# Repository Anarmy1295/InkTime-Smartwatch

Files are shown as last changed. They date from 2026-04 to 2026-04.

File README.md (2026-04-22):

# InkTime-Smartwatch

An open-source smartwatch powered by the nRF52840 with an e-paper display, designed for low power consumption and BLE connectivity.



## Block Diagram

Untitled Diagram drawio

## BOM (Bill Of Materials) 
| Qty | Component | Value / Part | Package | Notes |
|-----|---|---|---|---|
| 3 | Buttons | EVP-AKE31A | SMD | SW_DN, SW_ENT, SW_UP |
| 1 | Solder Jumper | SJ1 | SMD | Configuration jumper |
| 3 | Resistor | 7.68kΩ | 0201 | R2, R3, R4 |
| 4 | Capacitor | 0.1µF | 0201 | Decoupling |
| 1 | Capacitor | 0.1µF / 50V | 0402 | EPD |
| 1 | Resistor | 0Ω / 0.47Ω | 0201 | EPD driver |
| 1 | Capacitor | 1µF | 0402 | General |
| 5 | Capacitor | 100nF | 0402 | Decoupling |
| 1 | Capacitor | 100pF | 0402 | Filtering |
| 6 | Resistor | 10kΩ | 0201 | Pull-ups / general |
| 1 | Capacitor | 10µF | 0201 | Bulk |
| 2 | Capacitor | 10µF | 0402 | Power |
| 1 | Inductor | 10µH | 0402 | DC/DC |
| 4 | Capacitor | 12pF | 0402 | Crystal load |
| 1 | Inductor | 15nH | 0402 | RF matching |
| 2 | Capacitor | 1pF | 0402 | RF |
| 6 | Capacitor | 1µF | 0201 | Decoupling |
| 9 | Capacitor | 1µF / 50V | 0402 | EPD |
| 1 | Resistor | 2.2kΩ | 0201 | Config |
| 1 | PMOS | DMG2305UX | SOT-23 | Power switching |
| 2 | Capacitor | 22µF | 0402 | Power rail |
| 1 | Antenna | 2450AT18B100E | 1206 | 2.4GHz |
| 1 | Inductor | 3.9nH | 0402 | RF matching |
| 1 | Crystal | 32.768kHz | 3215 | RTC |
| 1 | Crystal | 32MHz | 2016 | MCU clock |
| 2 | Resistor | 3.3kΩ | 0201 | General |
| 1 | Capacitor | 4.7µF | 0402 | Bulk |
| 5 | Capacitor | 4.7µF | 0402 | Decoupling |
| 1 | Capacitor | 47nF | 0402 | Filtering |
| 1 | FPC Connector | 503480-2400 | SMD | Display |
| 2 | Resistor | 5.1kΩ | 0201 | USB-C CC |
| 1 | Inductor | 68µH | SMD | Power |
| 1 | Capacitor | 820pF | 0402 | Filtering |
| 1 | Accelerometer | BMA421 | LGA | Sensor |
| 1 | Charger IC | BQ25180YBGR | BGA | LiPo charger |
| 1 | Haptic Driver | DRV2605YZFR | BGA | Motor driver |
| 1 | Inductor | 0.47µH | 2012 | Power stage |
| 14 | Test Points | TP pads | PCB | Debug |
| 1 | USB-C | KH-TYPE-C-16P | SMD | Power |
| 1 | Fuel Gauge | MAX17048G+T10 | TDFN-8 | Battery monitor |
| 3 | Diode | MBR0530 | SOD-123 | Schottky |
| 3 | Capacitor | N.C. | 0402 | Not populated |
| 1 | MCU | nRF52840 | QFN | Main MCU |
| 1 | Buck-Boost | RT6160AWSC | WLCSP | 3.3V rail |
| 1 | NMOS | SI1308EDL | SOT-323 | Switching |
| 1 | Debug Connector | TC2030-IDC | PCB | SWD |
| 1 | ESD Protection | USBLC6-2SC6Y | SOT-23-6 | USB protection |

## Hardware Description

### MCU — nRF52840

The nRF52840 is the central processing unit of the system.

**Key features:**
- ARM Cortex-M4F @ 64 MHz (with FPU)
- Bluetooth Low Energy (BLE 5.0)
- USB 2.0 Full Speed
- 1 MB Flash / 256 KB RAM

All peripherals are connected via:
- I2C
- SPI
- GPIO

---

### Power Architecture

USB-C → BQ25180 (charger) → LiPo battery (AKY0106, 400 mAh)
→ 3.3V rail (VREG, for MCU and all peripherals)

Battery → RT6160AWSC (boost) → EPD high-voltage supply (VCOM, gate voltages)

#### BQ25180 (Charger IC)

- Charges the LiPo battery
- Provides system rail (VSYS)
- I2C communication with MCU
- Interrupt output for status/fault

#### RT6160 (Buck-Boost Regulator)

- Converts VSYS to stable 3.3V
- Powers:
  - MCU
  - sensors
  - display
  - haptic driver

#### MAX17048 (Fuel Gauge)

- Monitors battery voltage and state of charge
- I2C interface
- ALERT signal for battery events

---

### E-Paper Display

Controlled via SPI and GPIO.

#### Interface

| Signal | Direction | Description |
|---|---|---|
| SCK | MCU → Display | SPI clock |
| MOSI | MCU → Display | SPI data |
| EPD_CS | MCU → Display | Chip select |
| EPD_DC | MCU → Display | Data/Command |
| EPD_RST | MCU → Display | Reset |
| EPD_BUSY | Display → MCU | Status |

#### Power Stage

Includes:
- inductors
- Schottky diodes
- MOSFETs

Generates:
- PREVGH
- PREVGL

---

### IMU — BMA421

- Interface: I2C
- Features:
  - acceleration sensing
  - motion detection
  - step counting

**Interrupts:**
- INT1
- INT2

---

### Haptic Driver — DRV2605

- Interface: I2C
- Enable pin: `HAPTIC_EN`
- Function: vibration motor control

---

### USB Interface

- USB Type-C connector
- ESD protection: USBLC6-2SC6Y

**Signals:**
- VBUS
- D+
- D-

**Usage:**
- charging
- USB detection

---

### RF & Antenna

- 2.4 GHz chip antenna (2450AT18B100E)

**Design includes:**
- matching network
- antenna keepout
- no copper under antenna

---

### User Interface

3 buttons:
- Up
- Down
- Enter / Esc

- Connected to GPIO
- Active-low

---

### Debug Interface

SWD via Tag-Connect:

- SWDIO
- SWDCLK
- RESET
- SWO
- 3.3V
- GND

---

## Pin Mapping (nRF52840)

### I2C (Shared Bus)

| Pin | Function |
|-----|---|
| P0.06 | SDA |
| P0.07 | SCL |

Devices:
- BMA421
- MAX17048
- BQ25180
- RT6160
- DRV2605

---

### SPI (E-Paper Display)

| Pin | Function |
|-----|---|
| P0.02 | SCK |
| P0.03 | MOSI |
| P0.05 | CS |
| P0.15 | DC |
| P0.16 | RST |
| P0.17 | BUSY |

---

### Control & Interrupts

| Pin | Function |
|-----|---|
| P1.01 | Display power (PFET) |
| P0.08 | BMA421 INT1 |
| P1.08 | BMA421 INT2 |
| P0.10 | MAX17048 ALERT |
| P0.11 | Charger interrupt |
| P0.12 | Haptic enable |

---

### Buttons

| Pin | Function |
|-----|---|
| P0.13 | Up |
| P0.14 | Down |
| P1.00 | Enter / Esc |

---

### USB

| Signal | Function |
|---|---|
| D+ | Data |
| D- | Data |
| VBUS | Power detect |

---

### Clocks & Debug

- SWDIO / SWDCLK / RESET / SWO
- 32 MHz crystal (HFXO)
- 32.768 kHz crystal (LFXO)

---

## Design Considerations

- Use of dedicated hardware interfaces (I2C, SPI)
- Logical grouping of signals
- Simplified PCB routing
- Interrupt-driven architecture
- Clean debug interface

---

## Power Optimization

- MCU supports low-power modes
- E-paper consumes power only during refresh
- IMU is ultra low-power
- Haptic driver active only briefly

**Efficiency strategies:**
- enable peripherals only when needed
- regulated 3.3V rail
- independent control of display power

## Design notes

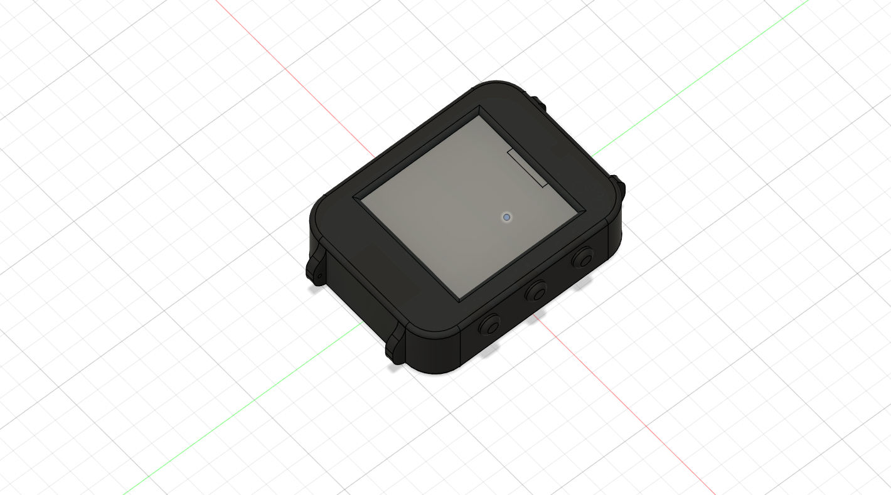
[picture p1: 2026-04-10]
Images/Case.png

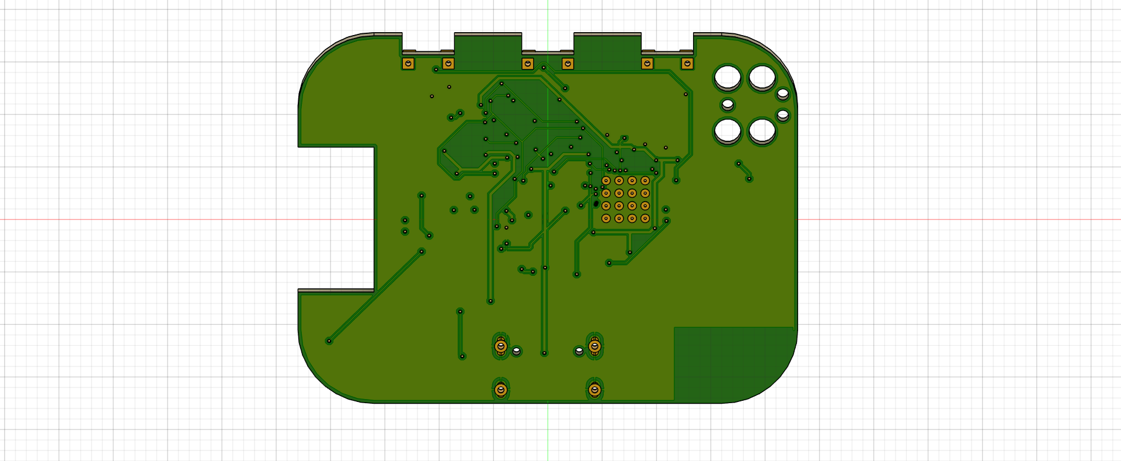
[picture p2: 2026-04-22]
Images/InkTime2.png

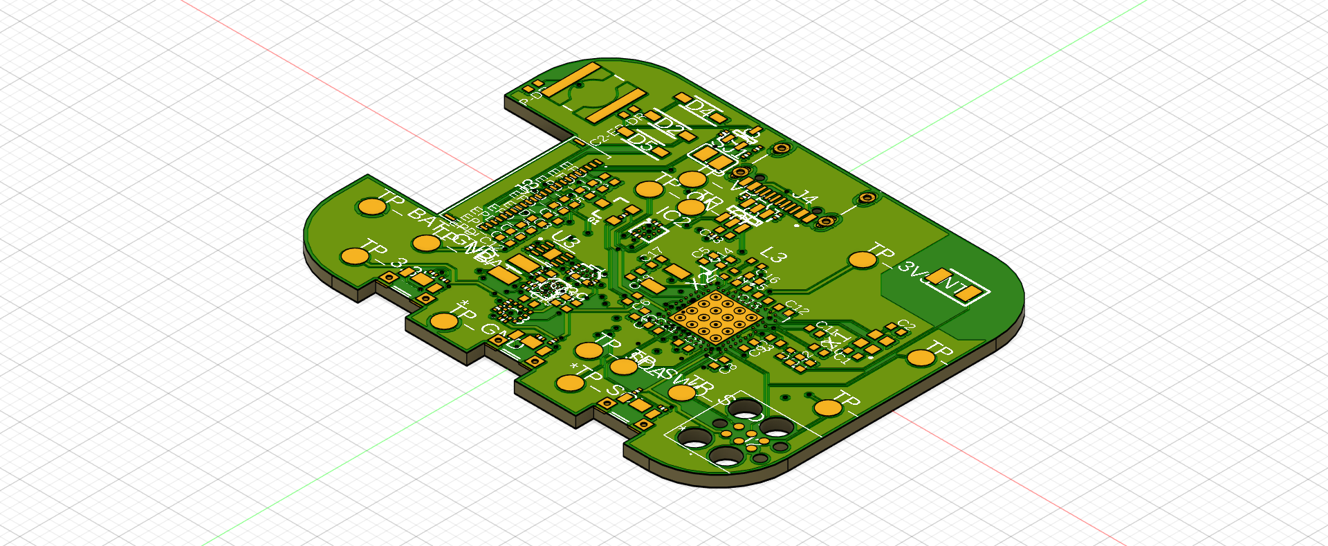
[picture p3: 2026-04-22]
Images/InkTime.png

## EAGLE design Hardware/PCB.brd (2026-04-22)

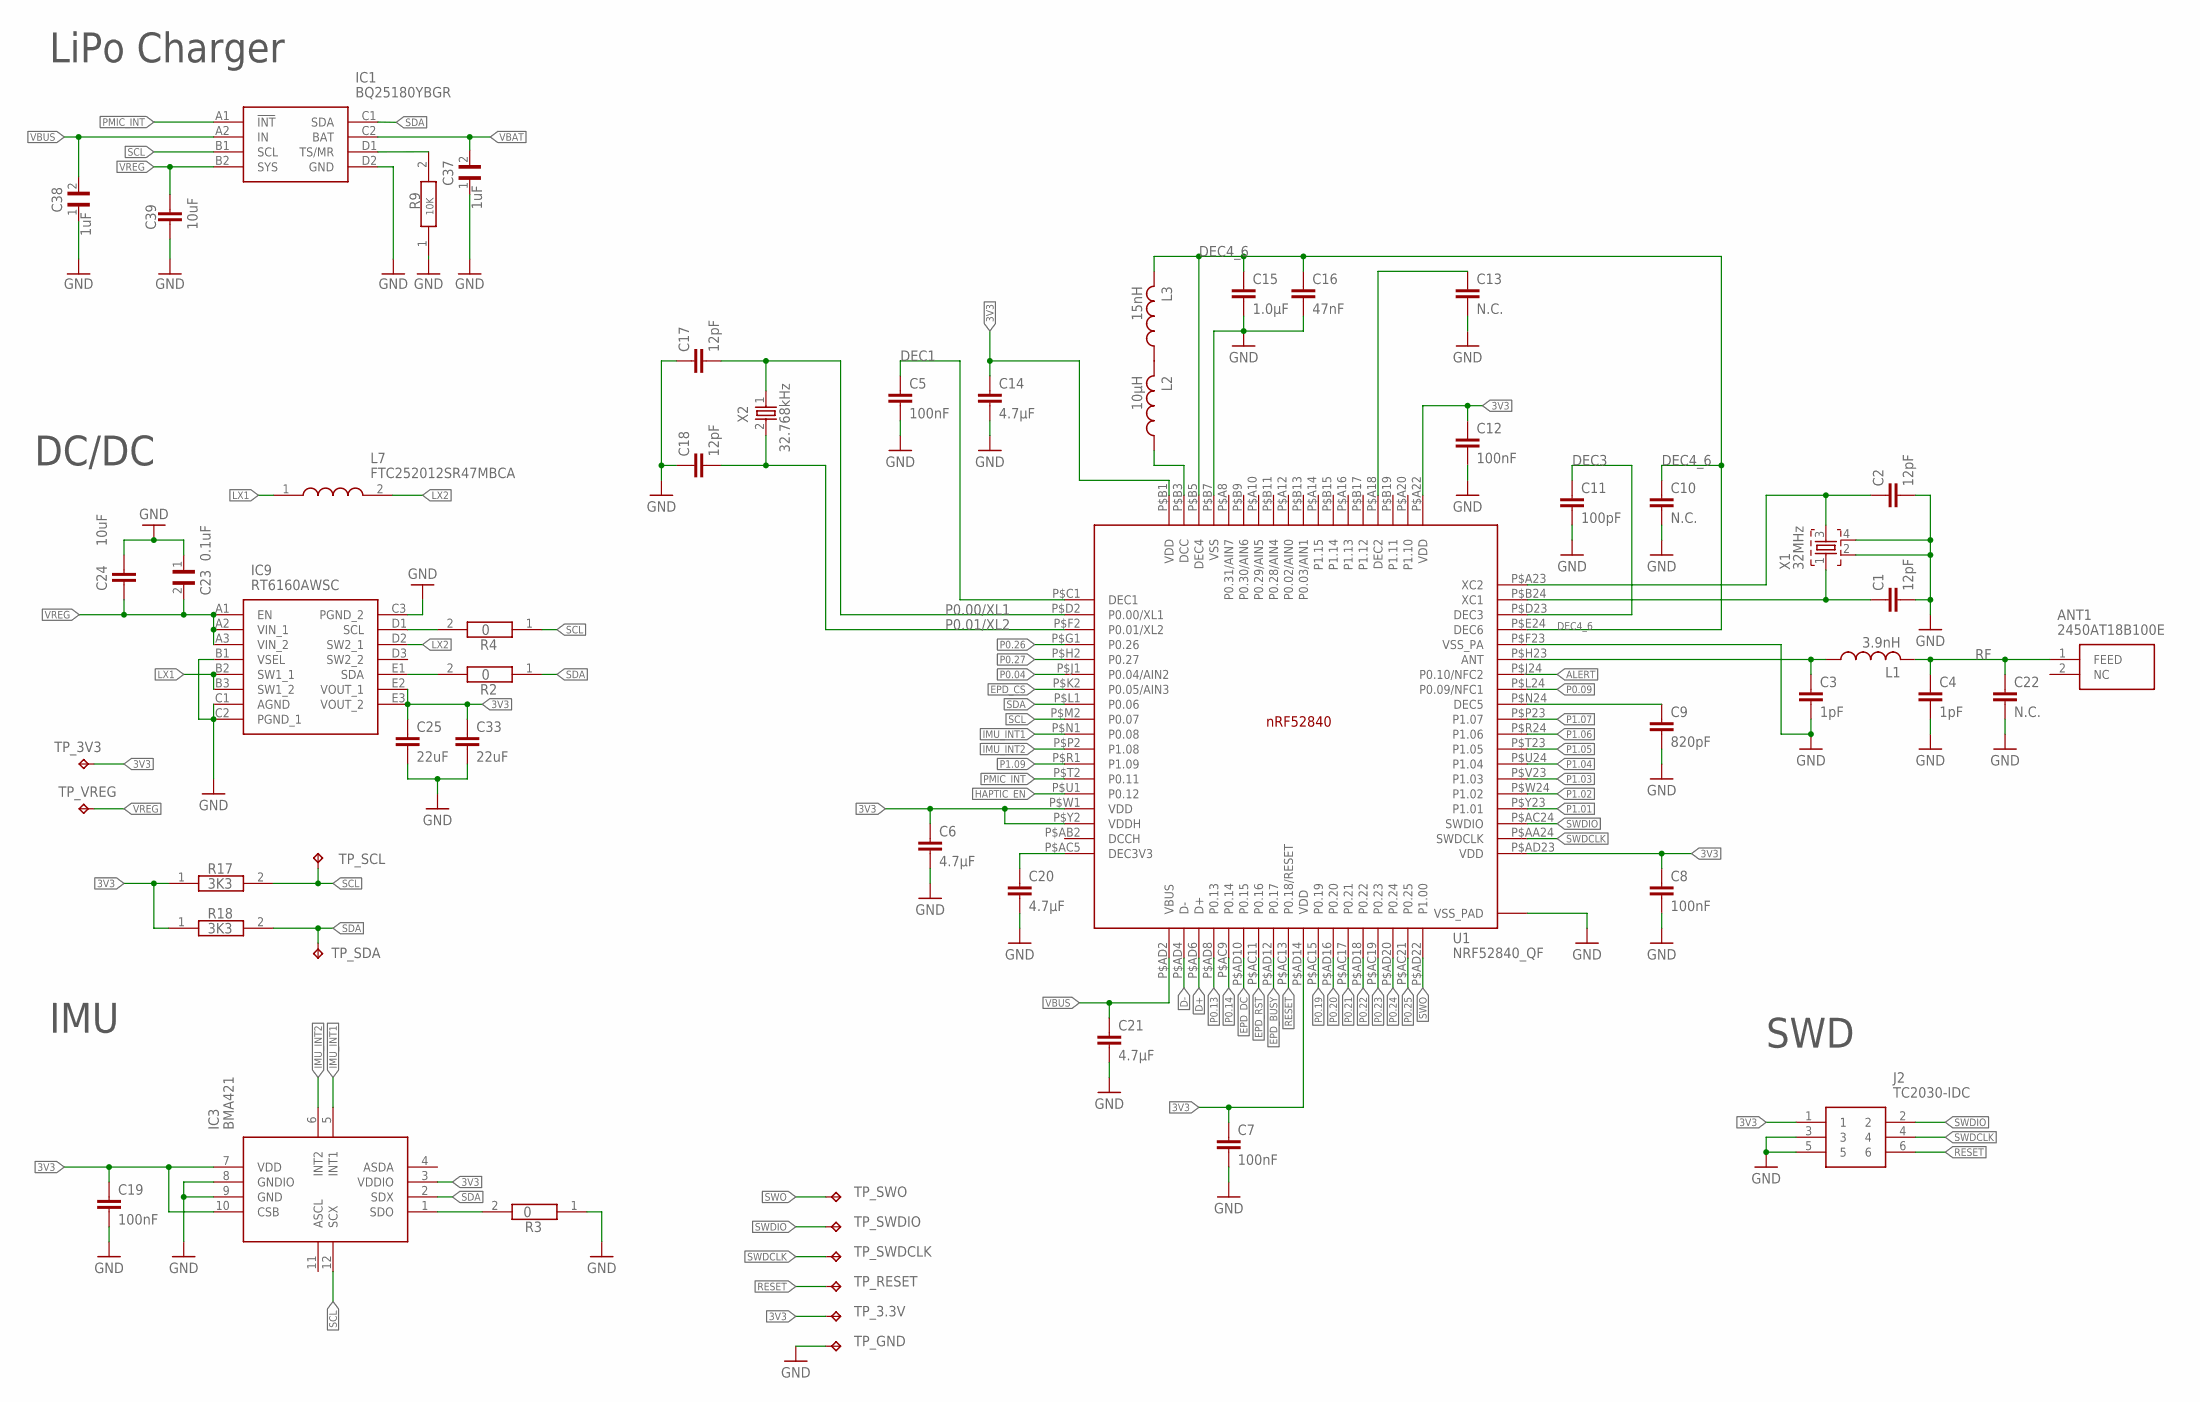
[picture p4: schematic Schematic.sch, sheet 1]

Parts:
ANT1: 2450AT18B100E; 2450AT18B100E_ANTC3216X140N
C1, C2, C17, C18: 12pF; PERFECT_0402_0402
C3, C4: 1pF; PERFECT_0402_0402
C5, C7, C8, C12, C19: 100nF; PERFECT_0402_0402
C6, C14, C20, C21: 4.7μF; PERFECT_0402_0402
C9: 820pF; PERFECT_0402_0402
C10, C13, C22: N.C.; PERFECT_0402_0402
C11: 100pF; PERFECT_0402_0402
C15: 1.0μF; PERFECT_0402_0402
C16: 47nF; PERFECT_0402_0402
C23: 0.1uF; GRM011R60J152KE01L_1_0201
C24: 10uF; PERFECT_0402_0402
C25, C33: 22uF; PERFECT_0402_0402
C37, C38: 1uF; GRM011R60J152KE01L_1_0201
C39: 10uF; NORDIC_NRF_3_RESC0402_N
IC1: BQ25180YBGR; BQ25180YBGR_BGA8C40P2X4_100X155X50
IC3: BMA421; BMA423_BMA423
IC9: RT6160AWSC; RT6160AWSC_BGA15C40P3X5_140X230X60
J2: TC2030-IDC; TC2030-IDC_TC2030IDC
L1: 3.9nH; NORDIC_NRF_2_RESC0402_L
L2: 10μH; NORDIC_NRF_2_RESC0402_L
L3: 15nH; NORDIC_NRF_2_RESC0402_L
L7: FTC252012SR47MBCA; MLP2016SR47MT0S1_INDC2016X100N
R2, R3, R4: 0; CPF0201D7K68C1_0201
R9: 10K; CPF0201D7K68C1_0201
R17, R18: 3K3; CPF0201D7K68C1_0201
TP_3.3V, TP_3V3: HECTOR_WATCH_1_TPTP20R; HECTOR_WATCH_1_TP20R
TP_GND: HECTOR_WATCH_1_TPTP20R; HECTOR_WATCH_1_TP20R
TP_RESET: HECTOR_WATCH_1_TPTP20R; HECTOR_WATCH_1_TP20R
TP_SCL: HECTOR_WATCH_1_TPTP20R; HECTOR_WATCH_1_TP20R
TP_SDA: HECTOR_WATCH_1_TPTP20R; HECTOR_WATCH_1_TP20R
TP_SWDCLK: HECTOR_WATCH_1_TPTP20R; HECTOR_WATCH_1_TP20R
TP_SWDIO: HECTOR_WATCH_1_TPTP20R; HECTOR_WATCH_1_TP20R
TP_SWO: HECTOR_WATCH_1_TPTP20R; HECTOR_WATCH_1_TP20R
TP_VREG: HECTOR_WATCH_1_TPTP20R; HECTOR_WATCH_1_TP20R
U1: NRF52840_QF; NORDIC_NRF_4_AQFN50P700X700X85_HS-74N
X1: 32MHz; NORDIC_NRF_BT-XTAL_2016_N
X2: 32.768kHz; NORDIC_NRF_1_XTAL_3215_N

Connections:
3V3: C6.1, C7.1, C8.1, C12.1, C14.1, C19.1, C25.1, C33.1, IC3.3 (VDDIO), IC3.7 (VDD), IC3.10 (CSB), IC9.E2 (VOUT_1), IC9.E3 (VOUT_2), J2.1, R17.1, R18.1, TP_3.3V.TP, TP_3V3.TP, U1.P$A22 (VDD), U1.P$AD14 (VDD), U1.P$AD23 (VDD), U1.P$B1 (VDD), U1.P$W1 (VDD), U1.P$Y2 (VDDH); also elsewhere on the board
ALERT: U1.P$J24 (P0.10/NFC2); also elsewhere on the board
D+: U1.P$AD6 (D+); also elsewhere on the board
D-: U1.P$AD4 (D-); also elsewhere on the board
DEC1: C5.1, U1.P$C1 (DEC1)
DEC3: C11.1, U1.P$D23 (DEC3)
DEC4_6: C10.1, C15.1, C16.1, L3.2, U1.P$B5 (DEC4), U1.P$E24 (DEC6)
EPD_BUSY: U1.P$AD12 (P0.17); also elsewhere on the board
EPD_CS: U1.P$K2 (P0.05/AIN3); also elsewhere on the board
EPD_DC: U1.P$AD10 (P0.15); also elsewhere on the board
EPD_RST: U1.P$AC11 (P0.16); also elsewhere on the board
GND: C1.2, C2.2, C3.2, C4.2, C5.2, C6.2, C7.2, C8.2, C9.2, C10.2, C11.2, C12.2, C13.2, C14.2, C15.2, C16.2, C17.1, C18.1, C19.2, C20.2, C21.2, C22.2, C23.1, C24.1, C25.2, C33.2, C37.1, C38.1, C39.2, IC1.D2 (GND), IC3.8 (GNDIO), IC3.9 (GND), IC9.B1 (VSEL), IC9.C1 (AGND), IC9.C2 (PGND_1), IC9.C3 (PGND_2), J2.3, J2.5, R3.1, R9.1, TP_GND.TP, U1.P$74 (VSS_PAD), U1.P$75 (VSS_PAD), U1.P$76 (VSS_PAD), U1.P$77 (VSS_PAD), U1.P$78 (VSS_PAD), U1.P$79 (VSS_PAD), U1.P$80 (VSS_PAD), U1.P$81 (VSS_PAD), U1.P$82 (VSS_PAD), U1.P$83 (VSS_PAD), U1.P$84 (VSS_PAD), U1.P$85 (VSS_PAD), U1.P$86 (VSS_PAD), U1.P$87 (VSS_PAD), U1.P$88 (VSS_PAD), U1.P$89 (VSS_PAD), U1.P$90 (VSS_PAD), U1.P$B7 (VSS), U1.P$F23 (VSS_PA), X1.2, X1.4; also elsewhere on the board
HAPTIC_EN: U1.P$U1 (P0.12); also elsewhere on the board
IMU_INT1: IC3.5 (INT1), U1.P$N1 (P0.08)
IMU_INT2: IC3.6 (INT2), U1.P$P2 (P1.08)
LX1: IC9.B2 (SW1_1), IC9.B3 (SW1_2), L7.1
LX2: IC9.D2 (SW2_1), L7.2
unnamed: IC9.D1 (SCL), R4.2
unnamed: IC9.E1 (SDA), R2.2
unnamed: IC1.D1 (TS/MR), R9.2
unnamed: C9.1, U1.P$N24 (DEC5)
unnamed: L2.2, L3.1
unnamed: C3.1, L1.1, U1.P$H23 (ANT)
unnamed: IC3.1 (SDO), R3.2
unnamed: L2.1, U1.P$B3 (DCC)
unnamed: C1.1, U1.P$B24 (XC1), X1.1
unnamed: C2.1, U1.P$A23 (XC2), X1.3
unnamed: C20.1, U1.P$AC5 (DEC3V3)
unnamed: C13.1, U1.P$A18 (DEC2)
P0.00/XL1: C17.2, U1.P$D2 (P0.00/XL1), X2.1
P0.01/XL2: C18.2, U1.P$F2 (P0.01/XL2), X2.2
P0.04: U1.P$J1 (P0.04/AIN2)
P0.09: U1.P$L24 (P0.09/NFC1)
P0.13: U1.P$AD8 (P0.13); also elsewhere on the board
P0.14: U1.P$AC9 (P0.14); also elsewhere on the board
P0.19: U1.P$AC15 (P0.19)
P0.20: U1.P$AD16 (P0.20)
P0.21: U1.P$AC17 (P0.21)
P0.22: U1.P$AD18 (P0.22)
P0.23: U1.P$AC19 (P0.23)
P0.24: U1.P$AD20 (P0.24)
P0.25: U1.P$AC21 (P0.25)
P0.26: U1.P$G1 (P0.26)
P0.27: U1.P$H2 (P0.27)
P1.01: U1.P$Y23 (P1.01); also elsewhere on the board
P1.02: U1.P$W24 (P1.02); also elsewhere on the board
P1.03: U1.P$V23 (P1.03)
P1.04: U1.P$U24 (P1.04)
P1.05: U1.P$T23 (P1.05)
P1.06: U1.P$R24 (P1.06)
P1.07: U1.P$P23 (P1.07)
P1.09: U1.P$R1 (P1.09)
PMIC_INT: IC1.A1 (!INT), U1.P$T2 (P0.11)
RESET: J2.6, TP_RESET.TP, U1.P$AC13 (P0.18/RESET)
RF: ANT1.1 (FEED), C4.1, C22.1, L1.2
SCL: IC1.B1 (SCL), IC3.12 (SCX), R4.1, R17.2, TP_SCL.TP, U1.P$M2 (P0.07); also elsewhere on the board
SDA: IC1.C1 (SDA), IC3.2 (SDX), R2.1, R18.2, TP_SDA.TP, U1.P$L1 (P0.06); also elsewhere on the board
SWDCLK: J2.4, TP_SWDCLK.TP, U1.P$AA24 (SWDCLK)
SWDIO: J2.2, TP_SWDIO.TP, U1.P$AC24 (SWDIO)
SWO: TP_SWO.TP, U1.P$AD22 (P1.00)
VBAT: C37.2, IC1.C2 (BAT); also elsewhere on the board
VBUS: C21.1, C38.2, IC1.A2 (IN), U1.P$AD2 (VBUS); also elsewhere on the board
VREG: C23.2, C24.2, C39.1, IC1.B2 (SYS), IC9.A1 (EN), IC9.A2 (VIN_1), IC9.A3 (VIN_2), TP_VREG.TP

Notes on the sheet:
LiPo Charger
DC/DC
IMU
SWD

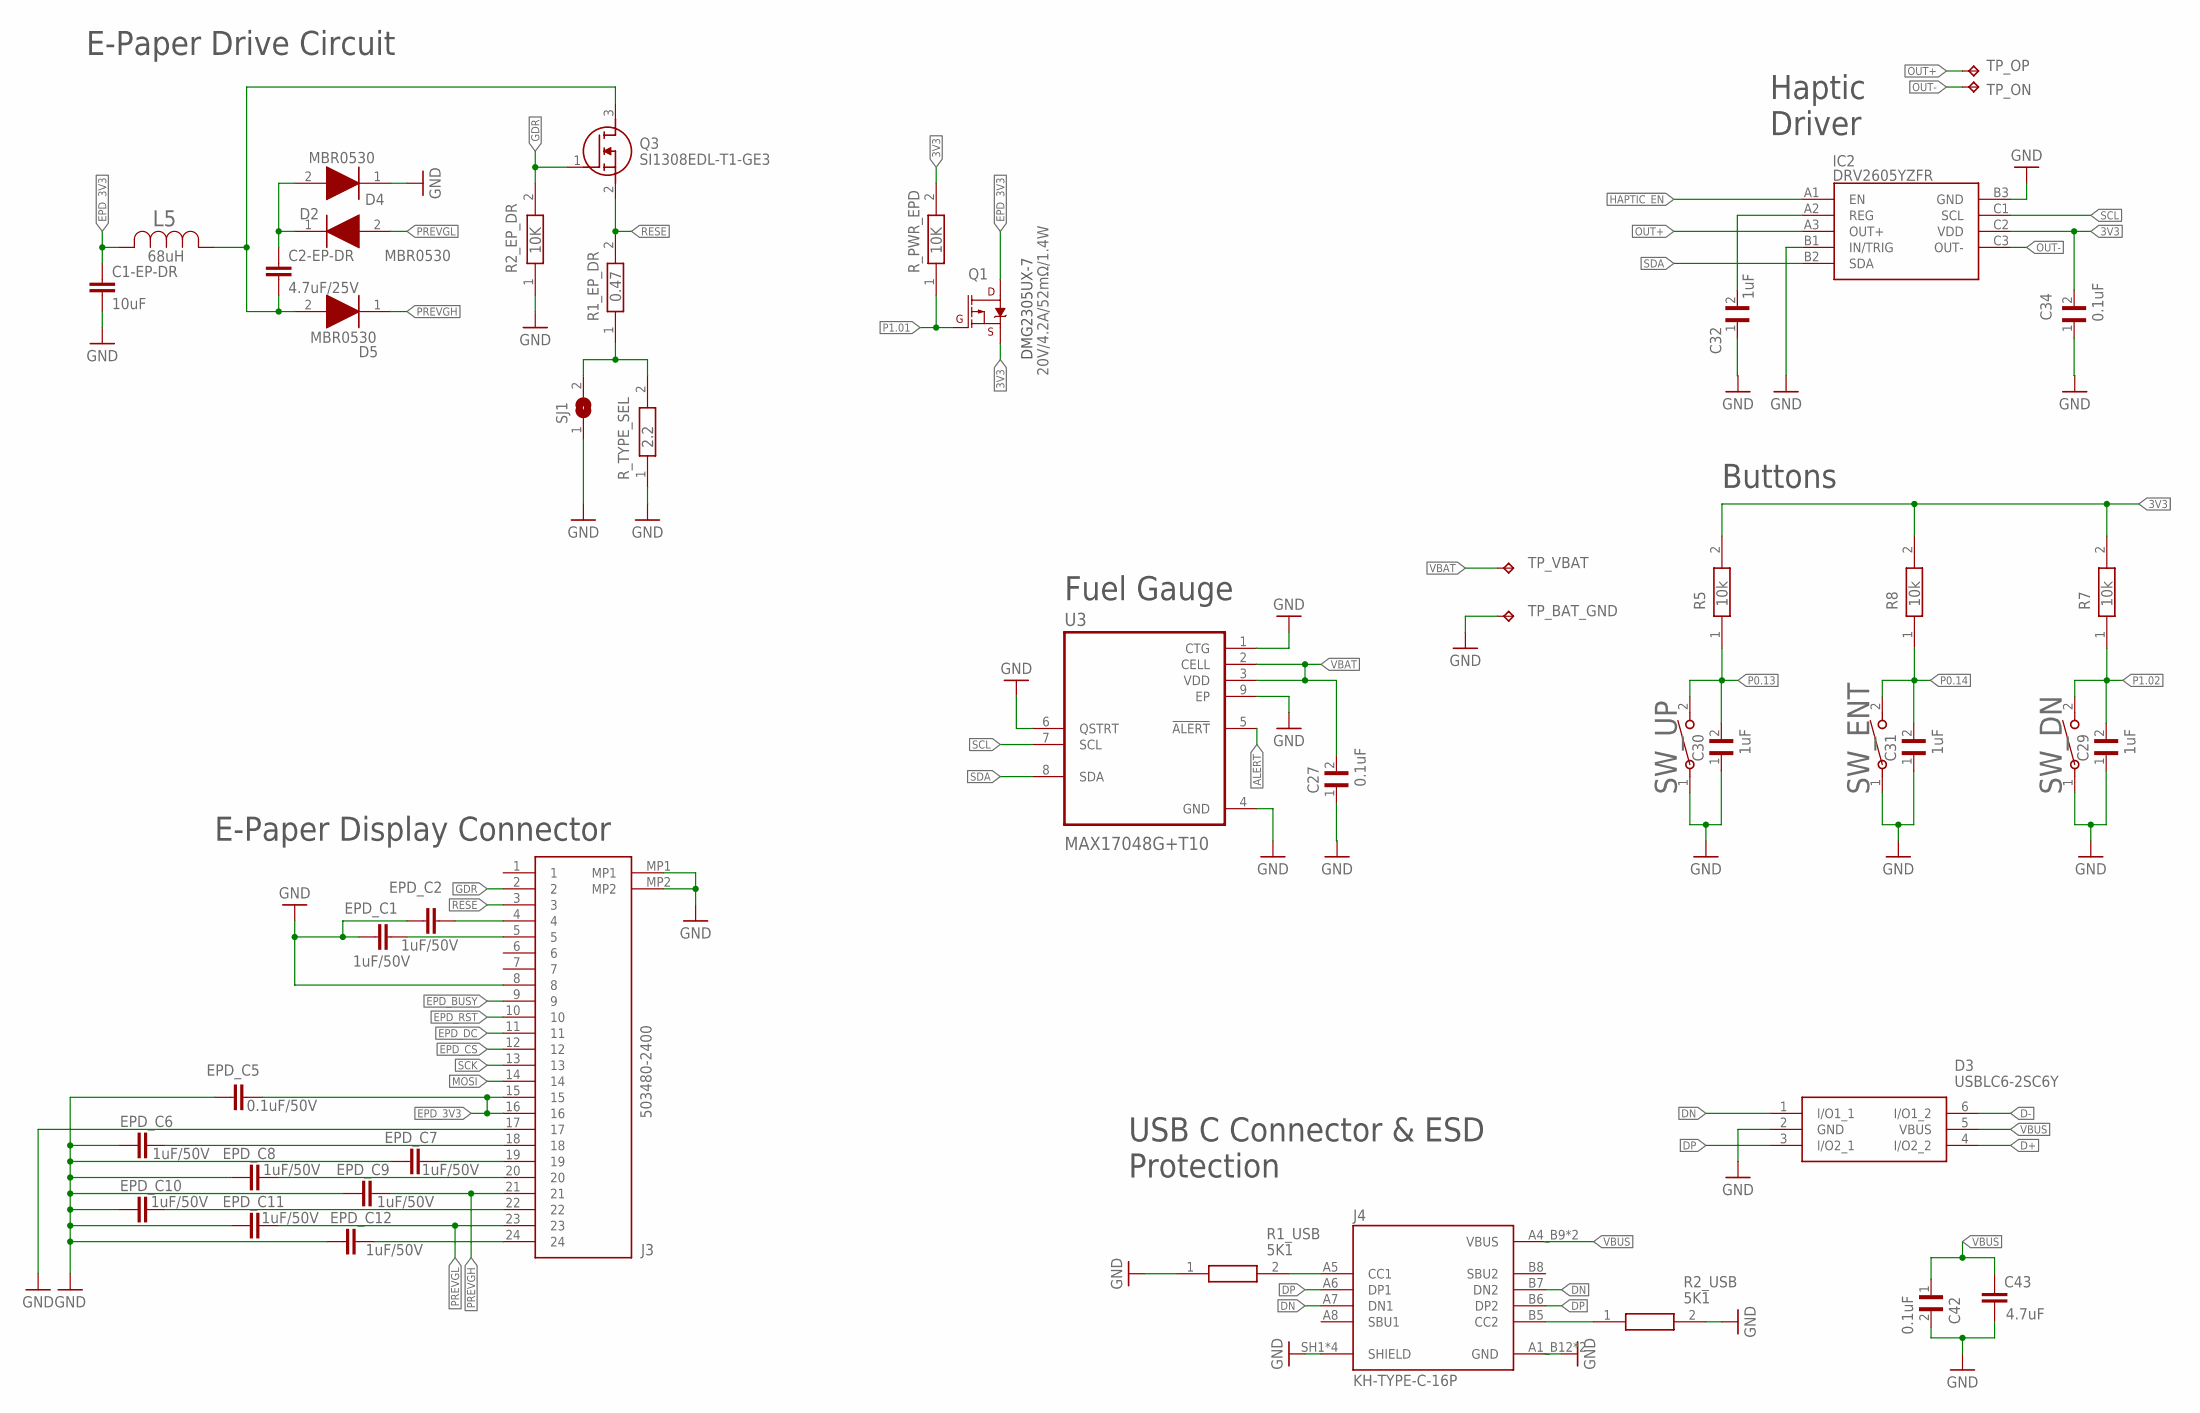
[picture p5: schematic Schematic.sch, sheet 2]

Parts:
C1-EP-DR: 10uF; PERFECT_0402_0402
C2-EP-DR: 4.7uF/25V; PERFECT_0402_0402
C27, C34, C42: 0.1uF; GRM011R60J152KE01L_1_0201
C29, C30, C31, C32: 1uF; GRM011R60J152KE01L_1_0201
C43: 4.7uF; PERFECT_0402_0402
D2, D4, D5: MBR0530; ESP32_C6_LIBRARY_5_SOD3716X135N
D3: USBLC6-2SC6Y; ESP32_C6_LIBRARY_3_SOT95P280X145-6N
EPD_C1, EPD_C2, EPD_C6, EPD_C7, EPD_C8, EPD_C9, EPD_C10, EPD_C11, EPD_C12: 1uF/50V; PERFECT_0402_0402
EPD_C5: 0.1uF/50V; PERFECT_0402_0402
IC2: DRV2605YZFR; DRV2605YZFR_BGA9C50P3X3_144X144X62
J3: 503480-2400; 503480-2400_5034802400
J4: KH-TYPE-C-16P; KH-TYPE-C-16P_KINGHELM_KH-TYPE-C-16P
L5: 68uH; ESP32_C6_LIBRARY_2_IND_4828-WE-TPC_WRE
Q1: 20V/4.2A/52mΩ/1.4W; ESP32_C6_LIBRARY_4_ESP32_C6_LIBRARY_4_ESP32_C6_LIBRARY_4_ES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
Q3: SI1308EDL-T1-GE3; ESP32_C6_LIBRARY_6_SOT65P210X110-3N
R1_EP_DR: 0.47; CPF0201D7K68C1_0201
R1_USB, R2_USB: 5K1; CPF0201D7K68C1_0201
R2_EP_DR: 10K; CPF0201D7K68C1_0201
R5, R7, R8: 10k; CPF0201D7K68C1_0201
R_PWR_EPD: 10K; CPF0201D7K68C1_0201
R_TYPE_SEL: 2.2; CPF0201D7K68C1_0201
SJ1: ESP32_C6_LIBRARY_7_JUMPER_SJ
SW_DN: 2025-10-22_07-23-44_LIBRARY_EVP-AKE31ASW_EVP-AKE3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; 2025-10-22_07-23-44_LIBRARY_SW_EVP-AKE31A_PAN
SW_ENT: 2025-10-22_07-23-44_LIBRARY_EVP-AKE31ASW_EVP-AKE3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; 2025-10-22_07-23-44_LIBRARY_SW_EVP-AKE31A_PAN
SW_UP: 2025-10-22_07-23-44_LIBRARY_EVP-AKE31ASW_EVP-AKE3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; 2025-10-22_07-23-44_LIBRARY_SW_EVP-AKE31A_PAN
TP_BAT_GND: HECTOR_WATCH_1_TPTP20R; HECTOR_WATCH_1_TP20R
TP_ON: HECTOR_WATCH_1_TPTP20R; HECTOR_WATCH_1_TP20R
TP_OP: HECTOR_WATCH_1_TPTP20R; HECTOR_WATCH_1_TP20R
TP_VBAT: HECTOR_WATCH_1_TPTP20R; HECTOR_WATCH_1_TP20R
U3: MAX17048G+T10; ESP32_C6_LIBRARY_SON50P200X200X80-9N

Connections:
3V3: C34.2, IC2.C2 (VDD), Q1.2 (S), R5.2, R7.2, R8.2, R_PWR_EPD.2; also elsewhere on the board
ALERT: U3.5 (!ALERT); also elsewhere on the board
D+: D3.4 (I/O2_2); also elsewhere on the board
D-: D3.6 (I/O1_2); also elsewhere on the board
DN: D3.1 (I/O1_1), J4.A7 (DN1), J4.B7 (DN2)
DP: D3.3 (I/O2_1), J4.A6 (DP1), J4.B6 (DP2)
EPD_3V3: C1-EP-DR.1, EPD_C5.2, J3.15, J3.16, L5.2, Q1.3 (D)
EPD_BUSY: J3.9; also elsewhere on the board
EPD_CS: J3.12; also elsewhere on the board
EPD_DC: J3.11; also elsewhere on the board
EPD_RST: J3.10; also elsewhere on the board
GDR: J3.2, Q3.1 (G), R2_EP_DR.2
GND: C1-EP-DR.2, C27.1, C29.1, C30.1, C31.1, C32.1, C34.1, C42.2, C43.1, D3.2 (GND), D4.1 (K), EPD_C1.1, EPD_C2.1, EPD_C5.1, EPD_C6.1, EPD_C7.1, EPD_C8.1, EPD_C9.1, EPD_C10.1, EPD_C11.1, EPD_C12.1, IC2.B1 (IN/TRIG), IC2.B3 (GND), J3.8, J3.17, J3.MP1, J3.MP2, J4.A1_B12 (GND), J4.A12_B1 (GND), J4.SH1 (SHIELD), J4.SH2 (SHIELD), J4.SH3 (SHIELD), J4.SH4 (SHIELD), R1_USB.1, R2_EP_DR.1, R2_USB.2, R_TYPE_SEL.1, SJ1.1, SW_DN.1, SW_ENT.1, SW_UP.1, TP_BAT_GND.TP, U3.1 (CTG), U3.4 (GND), U3.6 (QSTRT), U3.9 (EP); also elsewhere on the board
HAPTIC_EN: IC2.A1 (EN); also elsewhere on the board
MOSI: J3.14
unnamed: J4.B5 (CC2), R2_USB.1
unnamed: J4.A5 (CC1), R1_USB.2
unnamed: C2-EP-DR.2, D5.2 (A), L5.1, Q3.3 (D)
unnamed: C2-EP-DR.1, D2.1 (K), D4.2 (A)
unnamed: R1_EP_DR.1, R_TYPE_SEL.2, SJ1.2
unnamed: EPD_C1.2, J3.5
unnamed: EPD_C2.2, J3.4
unnamed: EPD_C6.2, J3.18
unnamed: EPD_C7.2, J3.19
unnamed: EPD_C8.2, J3.20
unnamed: EPD_C10.2, J3.22
unnamed: EPD_C12.2, J3.24
unnamed: C32.2, IC2.A2 (REG)
OUT+: IC2.A3 (OUT+), TP_OP.TP
OUT-: IC2.C3 (OUT-), TP_ON.TP
P0.13: C30.2, R5.1, SW_UP.2; also elsewhere on the board
P0.14: C31.2, R8.1, SW_ENT.2; also elsewhere on the board
P1.01: Q1.1 (G), R_PWR_EPD.1; also elsewhere on the board
P1.02: C29.2, R7.1, SW_DN.2; also elsewhere on the board
PREVGH: D5.1 (K), EPD_C9.2, J3.21
PREVGL: D2.2 (A), EPD_C11.2, J3.23
RESE: J3.3, Q3.2 (S), R1_EP_DR.2
SCK: J3.13
SCL: IC2.C1 (SCL), U3.7 (SCL); also elsewhere on the board
SDA: IC2.B2 (SDA), U3.8 (SDA); also elsewhere on the board
VBAT: C27.2, TP_VBAT.TP, U3.2 (CELL), U3.3 (VDD); also elsewhere on the board
VBUS: C42.1, C43.2, D3.5 (VBUS), J4.A4_B9 (VBUS), J4.A9_B4 (VBUS); also elsewhere on the board

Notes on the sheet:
E-Paper Drive Circuit
DMG2305UX-7
E-Paper Display Connector
Fuel Gauge
Haptic Driver
Buttons
USB C Connector & ESD Protection

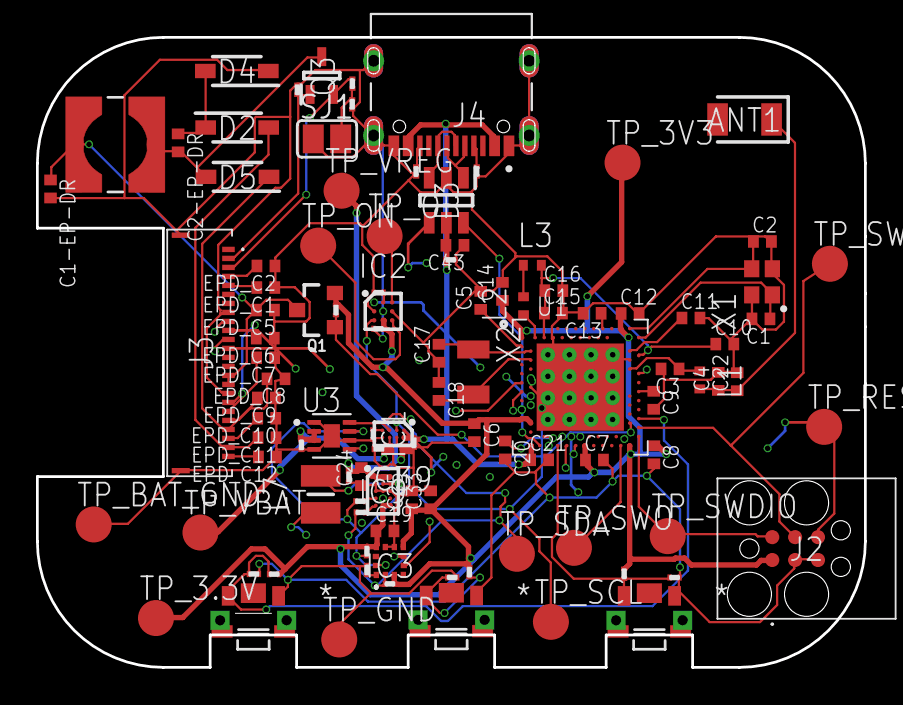
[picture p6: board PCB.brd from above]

Board: 4 copper layers, 46.0 x 35.0 mm, 105 parts (0 on the bottom side), 68 nets.

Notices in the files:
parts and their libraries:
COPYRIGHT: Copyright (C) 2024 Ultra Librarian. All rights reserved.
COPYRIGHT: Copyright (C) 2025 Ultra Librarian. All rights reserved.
